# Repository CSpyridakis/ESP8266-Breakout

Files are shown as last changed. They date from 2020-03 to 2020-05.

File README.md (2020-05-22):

# ESP8266-Breakout  

A breadboard-friendly ESP12E/F breakout with all I/O pins available, flash/reset buttons onboard, and place to directly use it with FTDI modules like [FT232RL FTDI Serial Adapter Module](https://www.banggood.com/FT232RL-FTDI-USB-To-TTL-Serial-Converter-Adapter-Module-p-917226.html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).

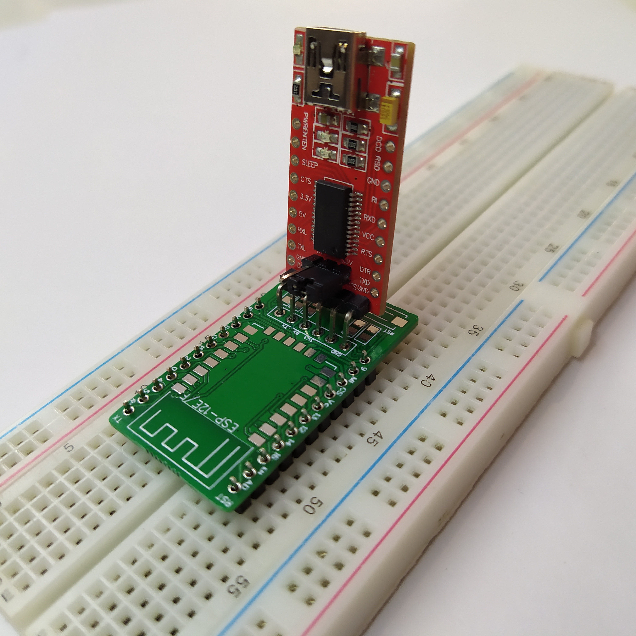
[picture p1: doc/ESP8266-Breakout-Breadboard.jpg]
ESP-Breakout-Breadboard


### Schematic
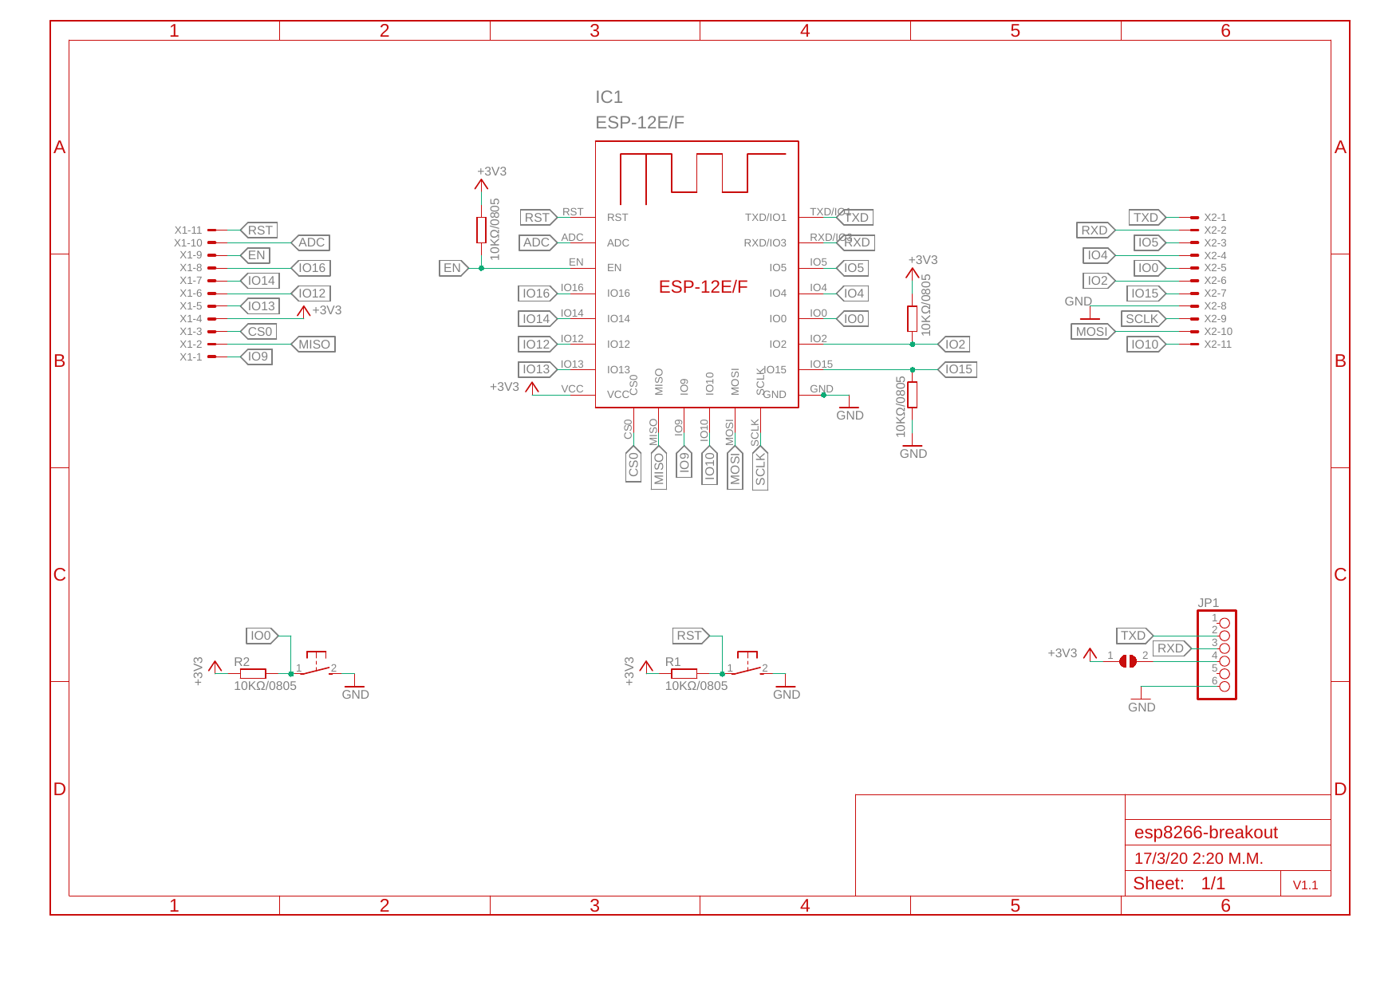
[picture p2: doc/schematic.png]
Schematic


|Top View |  Bottom View |
|:---:|:---:|
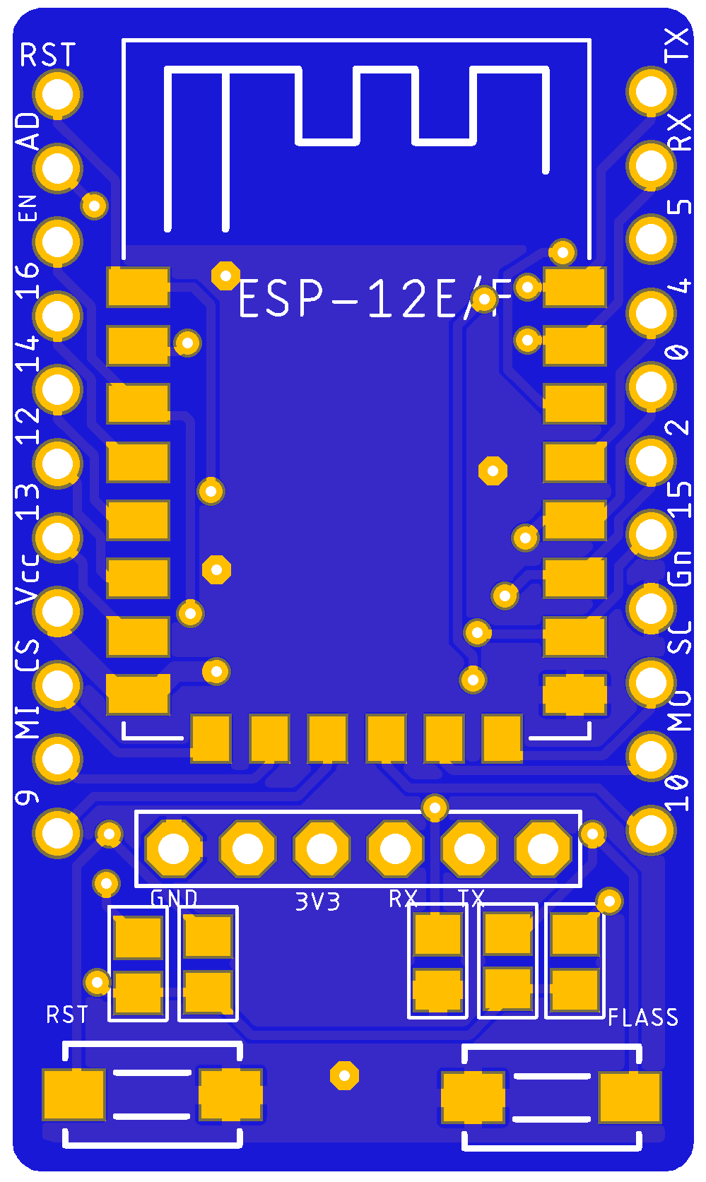
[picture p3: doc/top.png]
Top
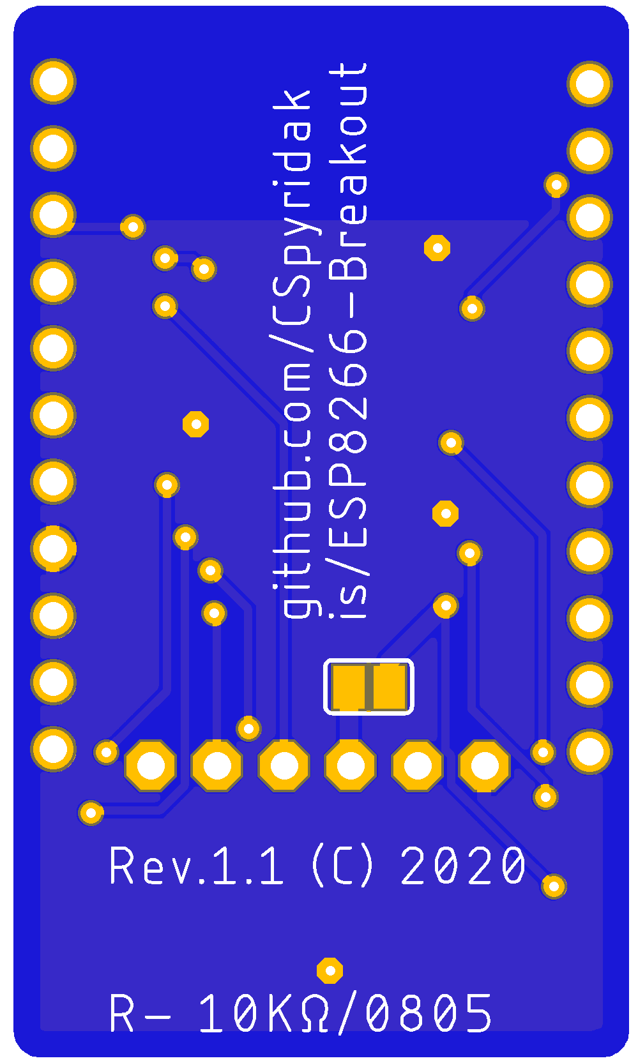
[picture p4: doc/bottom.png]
Bottom
|  |  |

### Sample
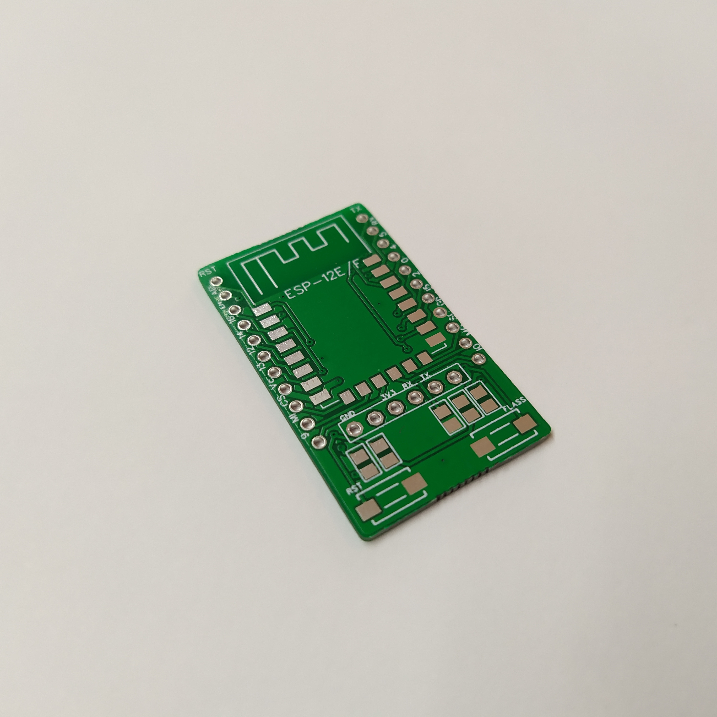
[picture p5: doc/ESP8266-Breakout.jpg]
PCB


## Assembly 
| No  | Component | Quantity |
|:---:|:---:|:---:|
| 1.  | ESP8266 - 12e/f | 1 | 
| 2.  | 10KΩ 0805 smd resistors | 5 | 
| 3.  | SMD-SWITCH-6.2MM | 2 |
| 4.  | Pin Header 1x11 Male 2.54 mm | 2 |

### Notes
* If you want to power up ESP8266-Breakout directly from a FTDI board, you need to solder the jumper that exists on the bottom side of the ESP8266-Breakout. **IMPORTANT:** Do not forget to change the jumper to 3.3V instead of 5V, on the FTDI module.
* If you want to use ESP8266-Breakout with a breadboard.
  - Connect Vcc to 3.3V
  - Connect Gn to Ground
  - You do not need to connect EN pin (ESP8266-Breakout itself has the required connection)
  - You do not need to add any extra pull-up or pull-down resistors on GPIO15, GPIO2 or GPIO0 for Boot Mode Selection

## PCB CAD tool
This project was developed using free version of  [EAGLE 9.5.2](https://www.autodesk.com/products/eagle/overview)

Gerber files are available [here](pcb/gerber/)

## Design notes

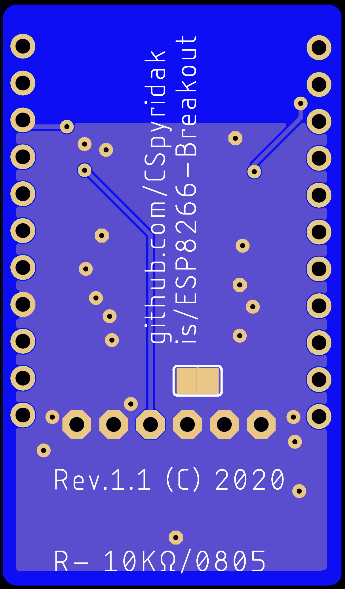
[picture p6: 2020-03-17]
doc/Bottom.png

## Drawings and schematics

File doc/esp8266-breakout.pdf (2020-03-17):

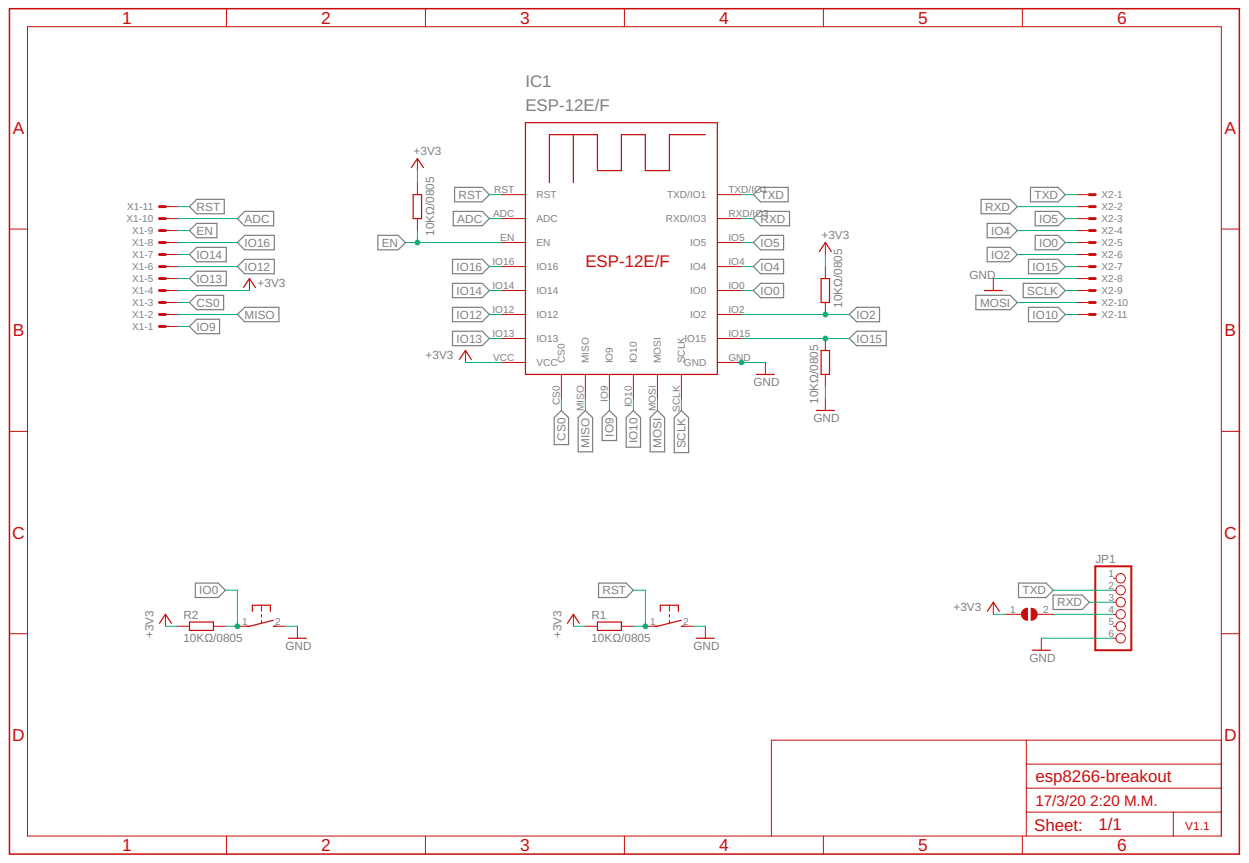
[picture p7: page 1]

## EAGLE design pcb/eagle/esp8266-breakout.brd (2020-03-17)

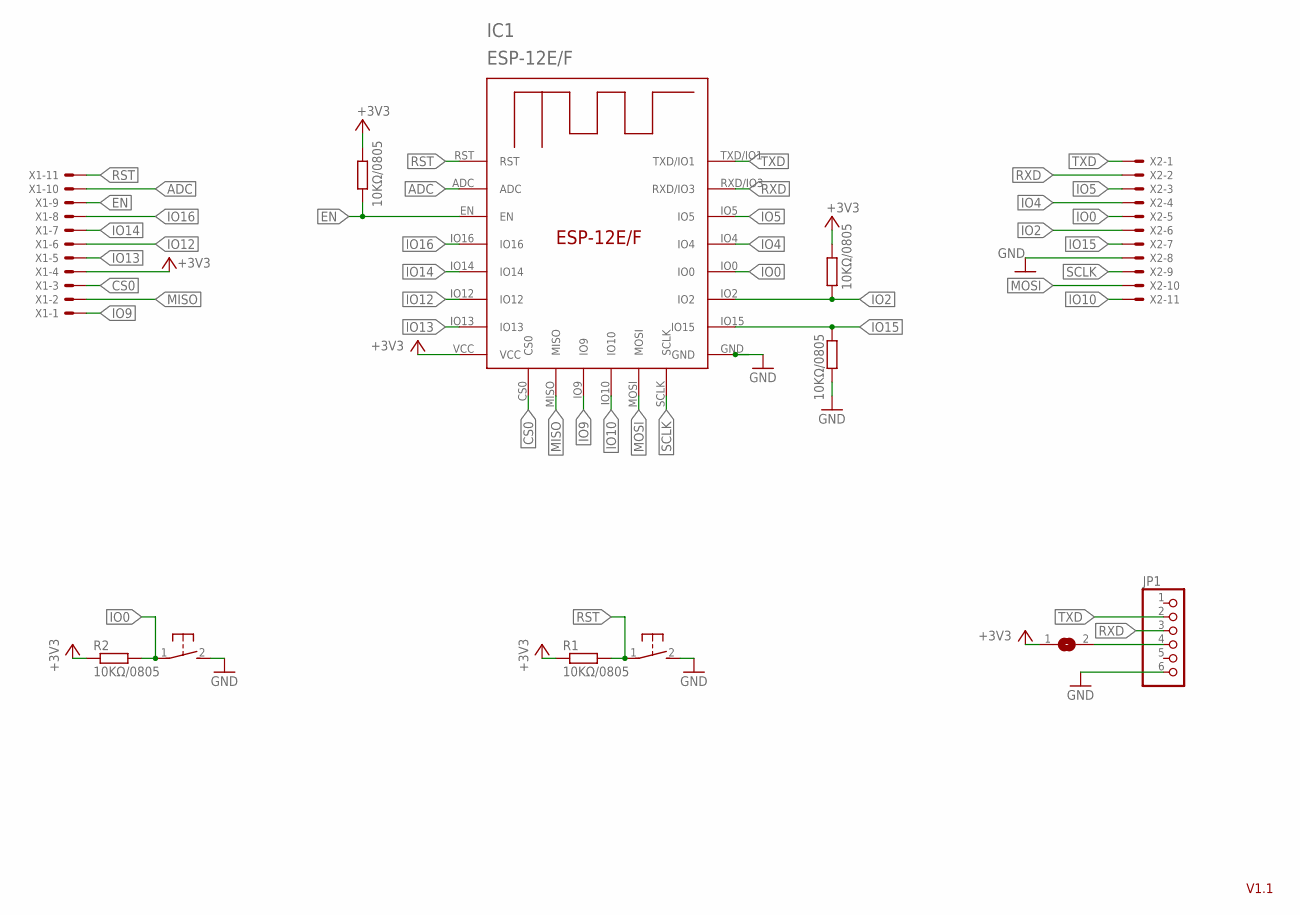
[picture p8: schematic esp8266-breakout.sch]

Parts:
IC1: ESP-12E/F; ESP-12E
JP1: PINHD-1X6B; 1X06-BIG
R1, R2, R3, R4, R5: 10KΩ/0805; R0805
S1, S2: DTSM-3
SJ1: SJ
X1, X2: JST-XH-11-PIN-ROUND-PAD; JST-XH-11-PACKAGE-ROUND-PAD

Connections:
+3V3: IC1.VCC, R1.1, R2.1, R4.1, R5.1, SJ1.1, X1.4
ADC: IC1.ADC, X1.10
CS0: IC1.CS0, X1.3
EN: IC1.EN, R5.2, X1.9
GND: IC1.GND, JP1.6, R3.2, S1.2, S2.2, X2.8
IO0: IC1.IO0, R2.2, S2.1, X2.5
IO2: IC1.IO2, R4.2, X2.6
IO4: IC1.IO4, X2.4
IO5: IC1.IO5, X2.3
IO9: IC1.IO9, X1.1
IO10: IC1.IO10, X2.11
IO12: IC1.IO12, X1.6
IO13: IC1.IO13, X1.5
IO14: IC1.IO14, X1.7
IO15: IC1.IO15, R3.1, X2.7
IO16: IC1.IO16, X1.8
MISO: IC1.MISO, X1.2
MOSI: IC1.MOSI, X2.10
unnamed: JP1.4, SJ1.2
RST: IC1.RST, R1.2, S1.1, X1.11
RXD: IC1.RXD/IO3, JP1.3, X2.2
SCLK: IC1.SCLK, X2.9
TXD: IC1.TXD/IO1, JP1.2, X2.1

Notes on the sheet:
V1.1

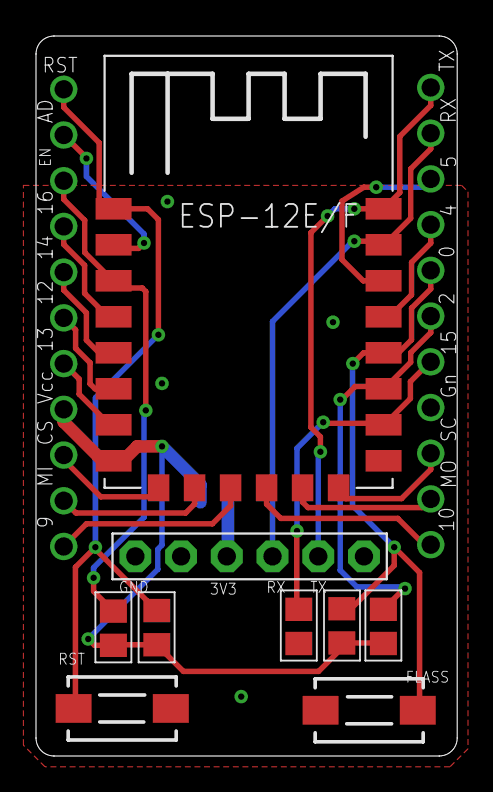
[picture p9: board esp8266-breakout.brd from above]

Board: 2 copper layers, 23.4 x 40.0 mm, 12 parts (1 on the bottom side), 23 nets.

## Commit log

2020-03-15 Pcb v1
    [esp8255-full-breakout.brd, esp8255-full-breakout.sch]
2020-03-17 Rev 1
    [esp8255-full-breakout.brd, esp8255-full-breakout.sch]
2020-03-17 Minor changes
    [esp8255-full-breakout.brd, esp8255-full-breakout.sch]
2020-03-17 Round corners added
    [esp8255-full-breakout.brd]
2020-03-17 Version 1.1
    [esp8255-full-breakout.brd]
2020-03-17 V1.1 Done
    [esp8266-breakout.brd, esp8266-breakout.sch]
2020-03-17 Remove BUs, Rev 1.1 Completed (TODO recheck)
    [esp8266-breakout.brd]
2020-03-17 Added perimeter on resistors
    [esp8266-breakout.brd]
2020-05-03 Top/Bottom pcb photos updated

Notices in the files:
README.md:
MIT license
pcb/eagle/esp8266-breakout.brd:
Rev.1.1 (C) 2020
